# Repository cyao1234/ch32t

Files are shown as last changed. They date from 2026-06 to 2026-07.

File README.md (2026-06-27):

# C32 Devboard

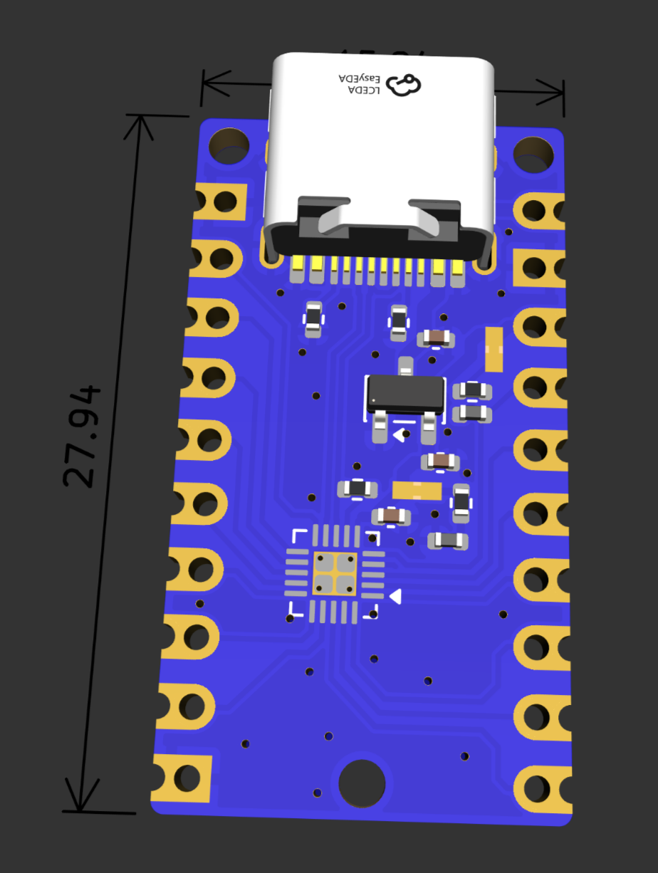
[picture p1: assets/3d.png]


Welp, what else than a tiny c32 devboard? A tiny ch32 device on your fingertips

Features:
- 2 leds
- Low cost
- tiny form
- Nothing much
- USB bootloader via rv003usb
- OPAMPs
- 12 bit ADCs

Everything is also open source, you can see it all in this repo.

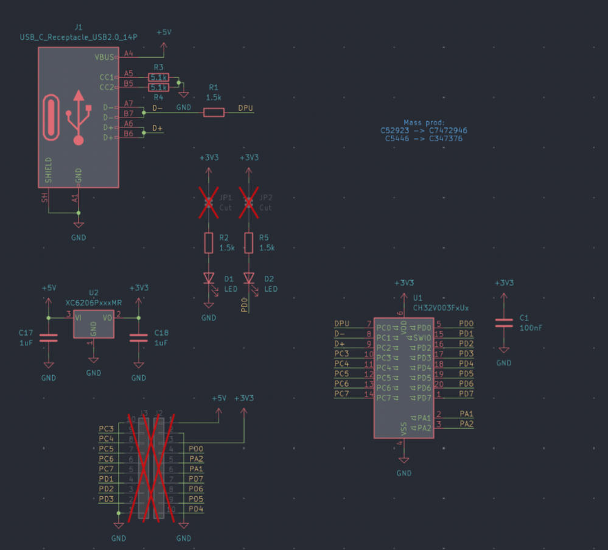
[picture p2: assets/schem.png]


The PCB uses a dual layer board in order to save costs, but still maintains a solid ground plane on the back side. It also has an embedded 3v3 ldo.

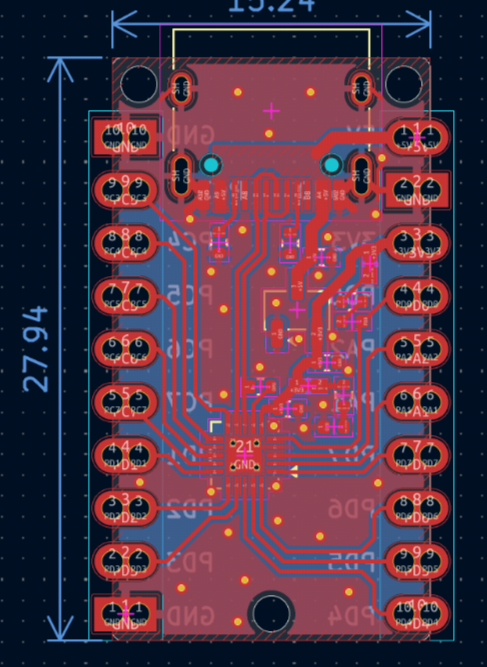
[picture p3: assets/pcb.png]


| Thing | Cost |
| ----- | ---- |
| PCB + PCBA | $115 |

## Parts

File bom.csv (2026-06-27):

Item | Cost | Link
PCB + PCBA | $115 | jlc

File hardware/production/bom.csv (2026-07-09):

Designator | Footprint | Quantity | Value | LCSC Part #
C1 | 0402 | 1 | 100nF | C307331
C17, C18 | 0402 | 2 | 1uF | C52923
J1 | USB_C_Receptacle_HRO_TYPE-C-31-M-12 | 1 | USB_C_Receptacle_USB2.0_14P | C393939
R1 | 0402 | 1 | 1.5k | C25867
R3, R4 | 0402 | 2 | 5.1k | C25905
U1 | QFN-20-1EP_3x3mm_P0.4mm_EP1.65x1.65mm_ThermalVias | 1 | CH32V003FxUx | C5299908
U2 | SOT-23-3 | 1 | XC6206PxxxMR | C5446

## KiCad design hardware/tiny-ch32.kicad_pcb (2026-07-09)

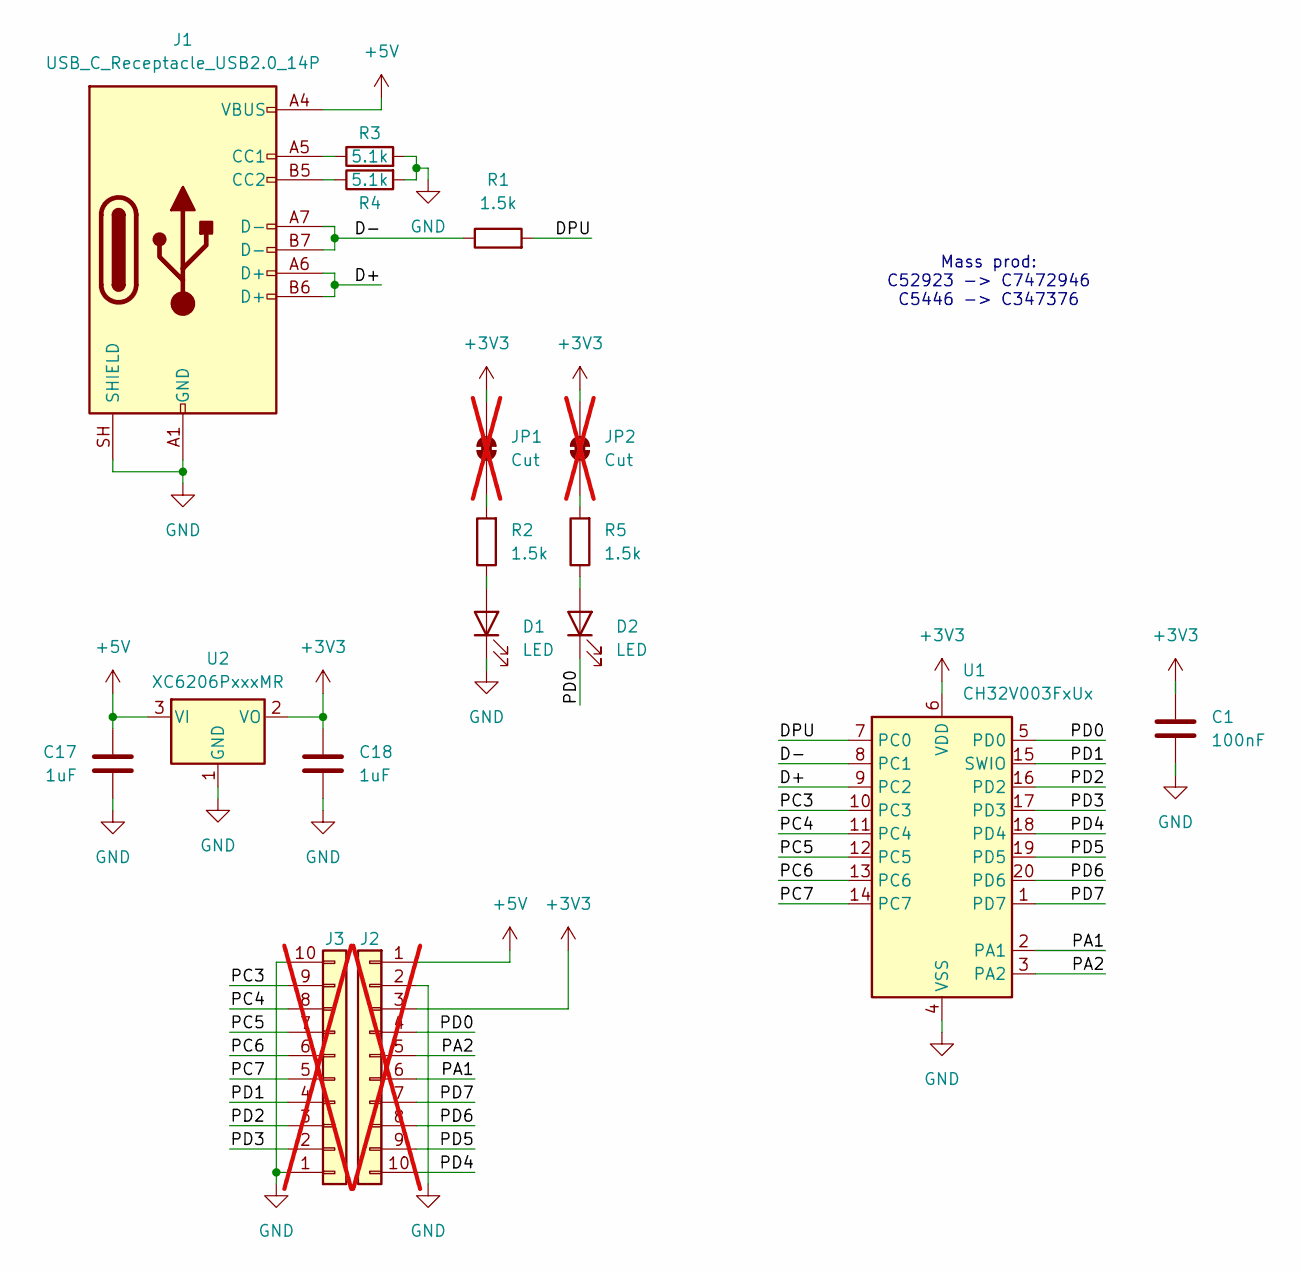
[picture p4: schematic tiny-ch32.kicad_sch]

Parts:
C1: 100nF; C_0402_1005Metric; LCSC Part # C307331
C17, C18: 1uF; C_0402_1005Metric; LCSC Part # C52923
D1, D2: LED; LED_0402_1005Metric; LCSC Part # C965793
J1: USB_C_Receptacle_USB2.0_14P; USB_C_Receptacle_HRO_TYPE-C-31-M-12; LCSC Part # C393939
J2, J3: Conn_01x10; Castellated_1x10_P2.54mm_Vertical; not fitted
JP1, JP2: Cut; SolderJumper-2_Bridged_Pad_Small; not fitted
R1, R2, R5: 1.5k; R_0402_1005Metric; LCSC Part # C25867
R3, R4: 5.1k; R_0402_1005Metric; LCSC Part # C25905
U1: CH32V003FxUx; QFN-20-1EP_3x3mm_P0.4mm_EP1.65x1.65mm_ThermalVias; LCSC Part # C5299908
U2: XC6206PxxxMR; SOT-23-3; LCSC Part # C5446

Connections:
+3V3: C1.1, C18.1, J2.3, JP1.1 (A), JP2.1 (A), U1.6 (VDD), U2.2 (VO)
+5V: C17.1, J1.A4 (VBUS), J1.A9 (VBUS), J1.B4 (VBUS), J1.B9 (VBUS), J2.1, U2.3 (VI)
/D+: J1.A6 (D+), J1.B6 (D+), U1.9 (PC2)
/D-: J1.A7 (D-), J1.B7 (D-), R1.1, U1.8 (PC1)
/DPU: R1.2, U1.7 (PC0)
/PA1: J2.6, U1.2 (PA1)
/PA2: J2.5, U1.3 (PA2)
/PC3: J3.9, U1.10 (PC3)
/PC4: J3.8, U1.11 (PC4)
/PC5: J3.7, U1.12 (PC5)
/PC6: J3.6, U1.13 (PC6)
/PC7: J3.5, U1.14 (PC7)
/PD0: D2.1 (K), J2.4, U1.5 (PD0)
/PD1: J3.4, U1.15 (SWIO)
/PD2: J3.3, U1.16 (PD2)
/PD3: J3.2, U1.17 (PD3)
/PD4: J2.10, U1.18 (PD4)
/PD5: J2.9, U1.19 (PD5)
/PD6: J2.8, U1.20 (PD6)
/PD7: J2.7, U1.1 (PD7)
GND: C1.2, C17.2, C18.2, D1.1 (K), J1.A1 (GND), J1.A12 (GND), J1.B1 (GND), J1.B12 (GND), J1.SH (SHIELD), J2.2, J3.1, J3.10, R3.2, R4.2, U1.4 (VSS), U1.21 (VSS), U2.1 (GND)
unnamed: D1.2 (A), R2.1
unnamed: D2.2 (A), R5.1
unnamed: J1.A5 (CC1), R3.1
unnamed: J1.B5 (CC2), R4.1
unnamed: JP1.2 (B), R2.2
unnamed: JP2.2 (B), R5.2

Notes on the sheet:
Mass prod: C52923 -> C7472946 C5446 -> C347376

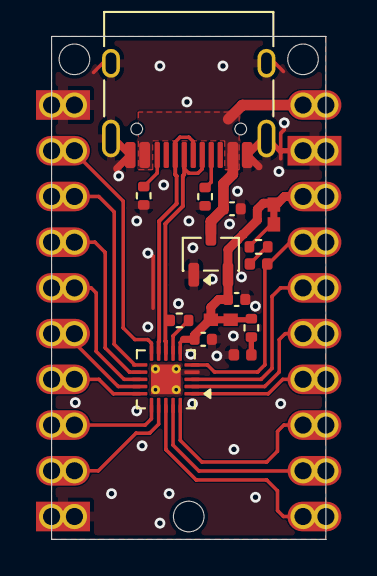
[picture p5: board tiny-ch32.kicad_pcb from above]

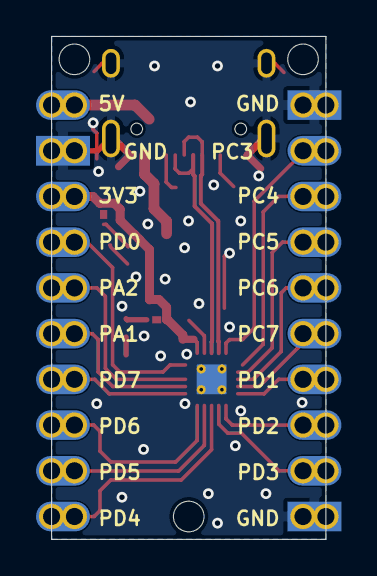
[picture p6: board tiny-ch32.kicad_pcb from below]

Board: 2 copper layers, 15.2 x 27.9 mm, 17 parts (2 on the bottom side), 27 nets.
